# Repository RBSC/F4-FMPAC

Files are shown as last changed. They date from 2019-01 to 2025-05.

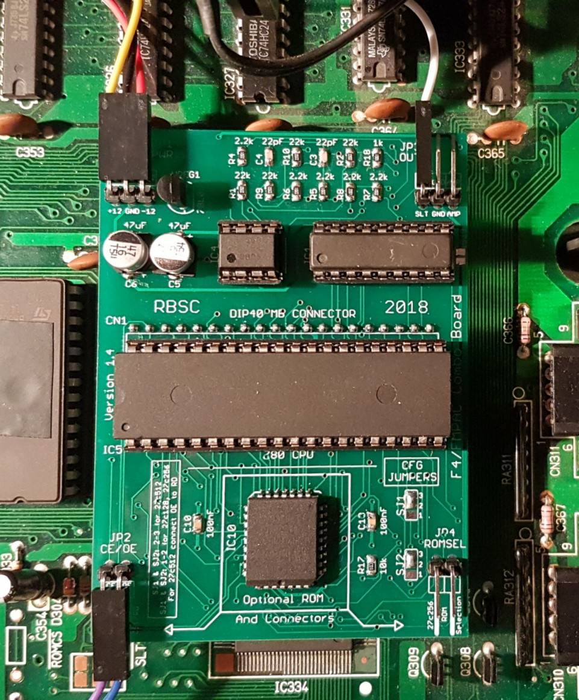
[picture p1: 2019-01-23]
Pics/assembled.jpg

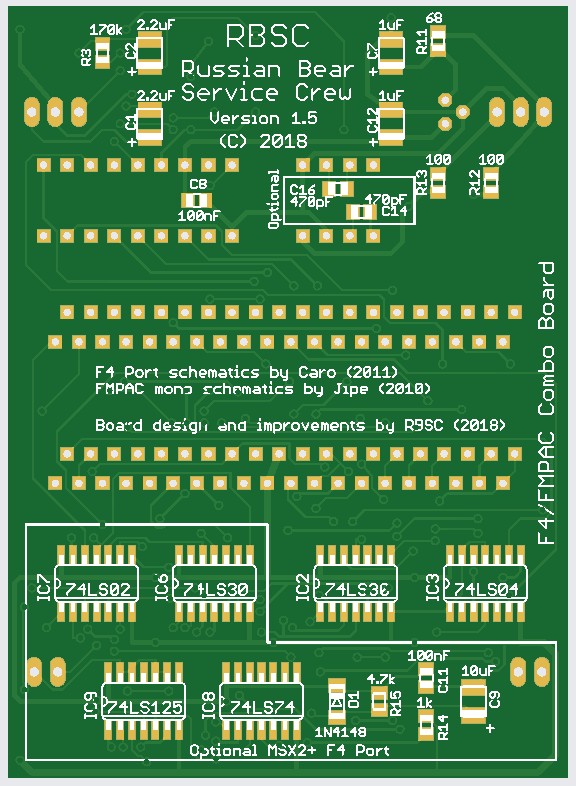
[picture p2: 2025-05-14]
Pics/board_back.jpg

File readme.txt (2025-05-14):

F4/FMPAC Combo Board version 1.5
Copyright (c) 2016-2025 RBSC
Portions (c) Kamil Karimov

Connection to the mainboard
---------------------------

The board requires a few wires to be connected to the MSX mainboard. The +12v and -12v are required for the FM chip and the
amplifier and must be connected to the JP1 connector. Also the GND (ground) must be connected to JP1, especially if the SJ3
solder jumper stays open. Those voltages and ground can be taken from the side slot of Yamaha MSX2 computers (YIS503, CX5M2
or CX7). On other computers those voltages could be taken from one of the slots or from the power supply's connection to the
mainboard.

The CE pin of the JP2 connector must be connected to the available STLSEL signal. On Yamaha MSX2 computers this could be taken
from the front slot (3.1). On other computers any unused slot signal could be used. The OE pin must be connected to CS1 signal
of the selected slot. However, in case of 27C512 EPROM installation, this pin must be connected to RD signal.

Audio connections
-----------------

The board has 2 different mono audio outputs marked as AMP and SLT. The AMP pin of JP3 must be only connected to the mixer point
of the internal amplifier, where all other SNDIN pins of cartridge slots are connected to. The AMP circuit already contains the
necessary resistor and capacitor and can be directly connected to the amplifier's input. To avoid interference from the other
components it's recommended to use the shielded wire. The shield should be connected to the GND pin of JP3.

The SLT pin of JP3 must be only connected to pin 49 (SNDIN) of any cartridge slot. On Yamaha MSX2 YIS503 and similar computers
the best place to connect the SLT pin is pin 59 on the side slot. Please be careful when connecting the wires - if not sure -
measure the voltages before connecting the wires. In correct connection could result in a damage for the board!

BIOS versions
-------------

The EPROM of the board contains 2 different FMPAC BIOSes. One is for external FMPAC (cartridge), the other is for internal FMPAC
(built-in into MSX2+). The BIOS is selected by JP4 jumper. It is recommended to use the internal FMPAC BIOS with the board. For
this option the jumper should not be installed.

Please pay special attention on the configuration notes on the board for solder jumpers SJ1 and SJ2! Those jumpers must be
configured correctly depending on the used EPROM chip. Otherwise FMPAC's BIOS will not work and there will be no FM music and
sounds in Basic as well as in certain games that detect the BIOS.

Notes
-----

The solderable jumper SJ3 is used to separate digital and analogue grounds. The board works fine without this jumper as long as
you connect the GND wire to JP1. The SJ3 should be only soldered if you don't connect GND to the board. But if you hear any
digital interference in the audio channel after you bridged the SJ3 jumper, please remove the bridge and connect GND wire to JP1.

The F4 Register part of the board is optional. It is only needed when the board is being installed into a computer that is converted
to MSX2+. Normal MSX1 or MSX2 computers don't need F4 port.

This FMPAC board does not support writing anything to SRAM (there's no SRAM on board). Also this device only provides mono sounds
and music. Stereo is not available.

Please note that the provided FMPAC BIOS image doesn't contain the UI (user interface). The full version of the FMPAC BIOS is
available in the RBSC's Carnivore2 cartridge. The BIOS is even translated into English.

IMPORTANT!
----------

The RBSC provides all the files and information for free, without any liability (see the disclaimer.txt file). The provided information,
software or hardware must not be used for commercial purposes unless permitted by the RBSC. Producing a small amount of bare boards for
personal projects and selling the rest of the batch is allowed without the permission of RBSC.

When the sources of the tools are used to create alternative projects, please always mention the original source and the copyright!

Contact information
-------------------

The members of RBSC group Tnt23, Wierzbowsky, Pyhesty, Ptero, GreyWolf, SuperMax, VWarlock, Alspru and DJS3000 can be contacted via the
group's e-mail address:

info@rbsc.su

The group's coordinator could be reached via this e-mail address:

admin@rbsc.su

The group's website can be found here:

https://rbsc.su/
https://rbsc.su/ru

The RBSC's hardware repository can be found here:

https://github.com/rbsc

The RBSC's 3D model repository can be found here:

https://www.thingiverse.com/groups/rbsc/things

-= ! MSX FOREVER ! =-

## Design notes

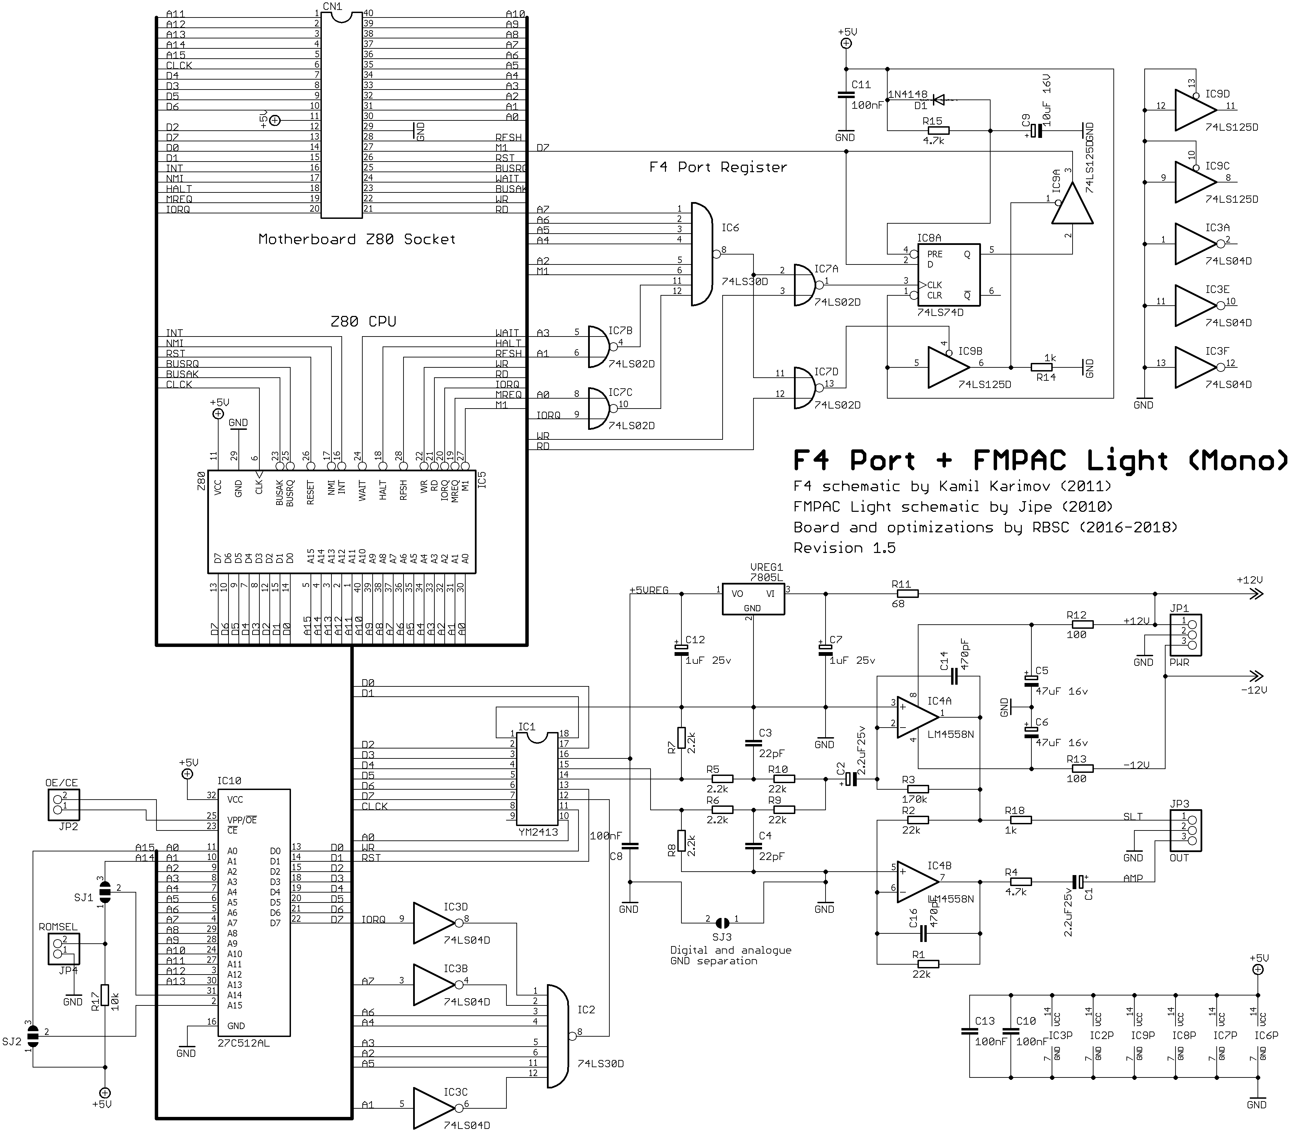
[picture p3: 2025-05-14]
Doc/schematics.png

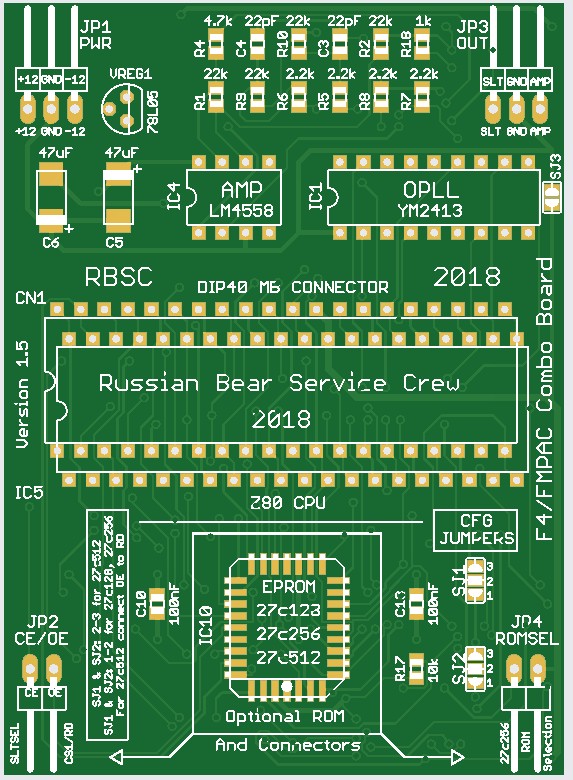
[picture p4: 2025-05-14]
Pics/board_front.jpg

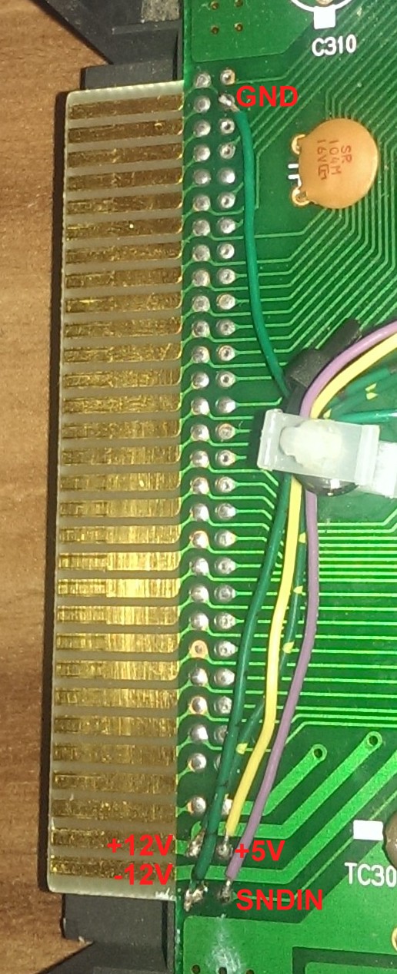
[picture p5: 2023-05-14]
Pics/sideslot.jpg

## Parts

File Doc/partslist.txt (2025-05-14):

Partlist

Part     Value          Device         Package  Library    Sheet

C1       2.2uF25v       CPOL-EUSMCB    SMC_B    rcl        1
C2       2.2uF25v       CPOL-EUSMCB    SMC_B    rcl        1
C3       22pF           C-EUC0805      C0805    rcl        1
C4       22pF           C-EUC0805      C0805    rcl        1
C5       47uF 16v       CPOL-EUSMCC    SMC_C    rcl        1
C6       47uF 16v       CPOL-EUSMCC    SMC_C    rcl        1
C7       1uF 25v        CPOL-EUSMCB    SMC_B    rcl        1
C8       100nF          C-EUC0805      C0805    rcl        1
C9       10uF 16V       CPOL-EUSMCB    SMC_B    rcl        1
C10      100nF          C-EUC0805      C0805    rcl        1
C11      100nF          C-EUC0805      C0805    rcl        1
C12      1uF 25v        CPOL-EUSMCB    SMC_B    rcl        1
C13      100nF          C-EUC0805      C0805    rcl        1
C14      470pF          C-EUC0805      C0805    rcl        1
C16      470pF          C-EUC0805      C0805    rcl        1
CN1      DIP40 MB CONN  DIL40          DIL40    ic-package 1
D1       1N4148         DIODE-MINIMELF MINIMELF diode      1
IC1      YM2413         DIL18          DIL18    ic-package 1
IC2      74LS30D        74LS30D        SO14     74xx-eu    1
IC3      74LS04D        74LS04D        SO14     74xx-eu    1
IC4      LM4558N        LM4558N        DIL08    linear     1
IC5      Z80            Z80CPU         DIL40    zilog      1
IC6      74LS30D        74LS30D        SO14     74xx-eu    1
IC7      74LS02D        74LS02D        SO14     74xx-eu    1
IC8      74LS74D        74LS74D        SO14     74xx-eu    1
IC9      74LS125D       74LS125D       SO14     74xx-eu    1
IC10     27C512AL       27C512AL       PLCC-32  microchip  1
JP1      PWR            PINHD-1X3/90   1X03/90  pinhead    1
JP2      OE/CE          PINHD-1X2/90   1X02/90  pinhead    1
JP3      OUT            PINHD-1X3/90   1X03/90  pinhead    1
JP4      ROMSEL         PINHD-1X2/90   1X02/90  pinhead    1
R1       22k            R-EU_R0805     R0805    rcl        1
R2       22k            R-EU_R0805     R0805    rcl        1
R3       170k           R-EU_R0805     R0805    rcl        1
R4       4.7k           R-EU_R0805     R0805    rcl        1
R5       2.2k           R-EU_R0805     R0805    rcl        1
R6       2.2k           R-EU_R0805     R0805    rcl        1
R7       2.2k           R-EU_R0805     R0805    rcl        1
R8       2.2k           R-EU_R0805     R0805    rcl        1
R9       22k            R-EU_R0805     R0805    rcl        1
R10      22k            R-EU_R0805     R0805    rcl        1
R11      68             R-EU_R0805     R0805    rcl        1
R12      100            R-EU_R0805     R0805    rcl        1
R13      100            R-EU_R0805     R0805    rcl        1
R14      1k             R-EU_R0805     R0805    rcl        1
R15      4.7k           R-EU_M0805     M0805    rcl        1
R17      10k            R-EU_R0805     R0805    rcl        1
R18      1k             R-EU_R0805     R0805    rcl        1
SJ1                     SJ2W           SJ_2     jumper     1
SJ2                     SJ2W           SJ_2     jumper     1
SJ3                     SJ             SJ       jumper     1
VREG1    7805L          7805L          TO92     linear     1

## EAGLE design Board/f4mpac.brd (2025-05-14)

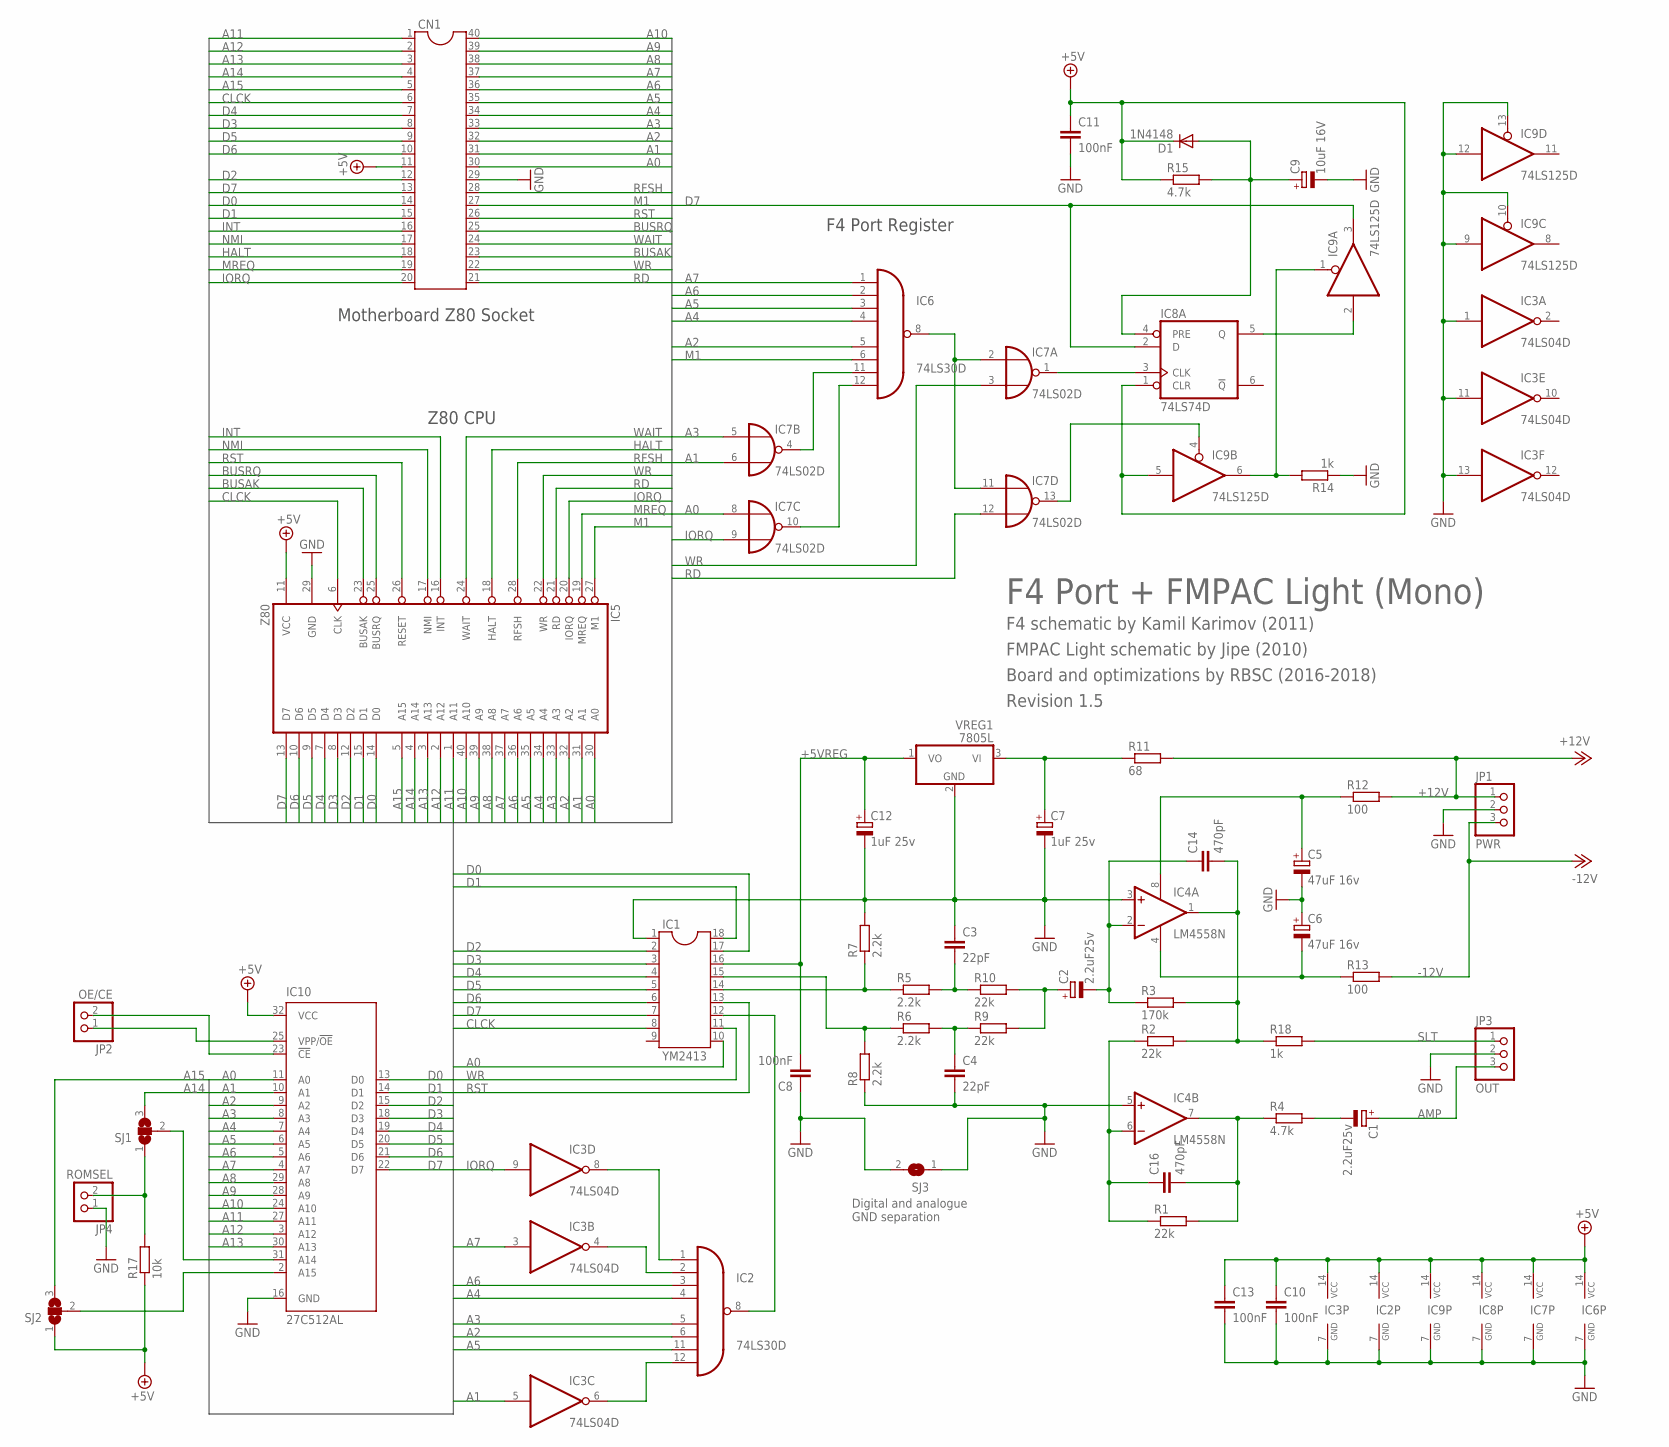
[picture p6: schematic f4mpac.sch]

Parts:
C1, C2: 2.2uF25v; SMC_B
C3, C4: 22pF; C0805
C5, C6: 47uF 16v; SMC_C
C7, C12: 1uF 25v; SMC_B
C8, C10, C11, C13: 100nF; C0805
C9: 10uF 16V; SMC_B
C14, C16: 470pF; C0805
CN1: DIP40 MB CONN; DIL40
D1: 1N4148; MINIMELF
IC1: YM2413; DIL18
IC2, IC6: 74LS30D; SO14
IC3: 74LS04D; SO14
IC4: LM4558N; DIL08
IC5: Z80; DIL40
IC7: 74LS02D; SO14
IC8: 74LS74D; SO14
IC9: 74LS125D; SO14
IC10: 27C512AL; PLCC-32
JP1: PWR; 1X03/90
JP2: OE/CE; 1X02/90
JP3: OUT; 1X03/90
JP4: ROMSEL; 1X02/90
R1, R2, R9, R10: 22k; R0805
R3: 170k; R0805
R4: 4.7k; R0805
R5, R6, R7, R8: 2.2k; R0805
R11: 68; R0805
R12, R13: 100; R0805
R14, R18: 1k; R0805
R15: 4.7k; M0805
R17: 10k; R0805
SJ1, SJ2: SJ2W; SJ_2
SJ3: SJ
VREG1: 7805L; TO92

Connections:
+5V: C10.1, C11.1, C13.1, CN1.11, D1.C, IC2.14 (VCC), IC3.14 (VCC), IC5.11 (VCC), IC6.14 (VCC), IC7.14 (VCC), IC8.1 (CLR), IC8.14 (VCC), IC9.5 (I), IC9.14 (VCC), IC10.32 (VCC), R15.1, R17.1, SJ2.1
+5VREG: C8.2, C12.+, IC1.16, VREG1.1 (VO)
+12V: JP1.1, R11.2, R12.2
+12VAMP: C5.+, IC4.8 (V+), R12.1
-12V: JP1.3, R13.2
-12VAMP: C6.-, IC4.4 (V-), R13.1
A0: CN1.30, IC1.10, IC5.30 (A0), IC7.8 (I0), IC10.11 (A0)
A1: CN1.31, IC3.5 (I), IC5.31 (A1), IC7.6 (I1), IC10.10 (A1)
A2: CN1.32, IC2.6 (I5), IC5.32 (A2), IC6.5 (I4), IC10.9 (A2)
A3: CN1.33, IC2.5 (I4), IC5.33 (A3), IC7.5 (I0), IC10.8 (A3)
A4: CN1.34, IC2.4 (I3), IC5.34 (A4), IC6.4 (I3), IC10.7 (A4)
A5: CN1.35, IC2.11 (I6), IC5.35 (A5), IC6.3 (I2), IC10.6 (A5)
A6: CN1.36, IC2.3 (I2), IC5.36 (A6), IC6.2 (I1), IC10.5 (A6)
A7: CN1.37, IC3.3 (I), IC5.37 (A7), IC6.1 (I0), IC10.4 (A7)
A8: CN1.38, IC5.38 (A8), IC10.29 (A8)
A9: CN1.39, IC5.39 (A9), IC10.28 (A9)
A10: CN1.40, IC5.40 (A10), IC10.24 (A10)
A11: CN1.1, IC5.1 (A11), IC10.27 (A11)
A12: CN1.2, IC5.2 (A12), IC10.3 (A12)
A13: CN1.3, IC5.3 (A13), IC10.30 (A13)
A14: CN1.4, IC5.4 (A14), SJ1.3
A15: CN1.5, IC5.5 (A15), SJ2.3
AMP: C1.+, JP3.3
BUSAK: CN1.23, IC5.23 (BUSAK)
BUSRQ: CN1.25, IC5.25 (BUSRQ)
CLCK: CN1.6, IC1.8, IC5.6 (CLK)
D0: CN1.14, IC1.17, IC5.14 (D0), IC10.13 (D0)
D1: CN1.15, IC1.18, IC5.15 (D1), IC10.14 (D1)
D2: CN1.12, IC1.2, IC5.12 (D2), IC10.15 (D2)
D3: CN1.8, IC1.3, IC5.8 (D3), IC10.18 (D3)
D4: CN1.7, IC1.4, IC5.7 (D4), IC10.19 (D4)
D5: CN1.9, IC1.5, IC5.9 (D5), IC10.20 (D5)
D6: CN1.10, IC1.6, IC5.10 (D6), IC10.21 (D6)
D7: CN1.13, IC1.7, IC5.13 (D7), IC8.2 (D), IC9.3 (O), IC10.22 (D7)
GND: C3.1, C4.2, C5.-, C6.+, C7.-, C8.1, C9.-, C10.2, C11.2, C12.-, C13.2, CN1.29, IC1.1, IC2.7 (GND), IC3.1 (I), IC3.7 (GND), IC3.11 (I), IC3.13 (I), IC4.3 (+IN), IC4.5 (+IN), IC5.29 (GND), IC6.7 (GND), IC7.7 (GND), IC8.7 (GND), IC9.7 (GND), IC9.9 (I), IC9.10 (OE), IC9.12 (I), IC9.13 (OE), IC10.16 (GND), JP1.2, JP3.2, JP4.1, R7.2, R8.1, R14.1, SJ3.1, SJ3.2, VREG1.2 (GND)
HALT: CN1.18, IC5.18 (HALT)
INT: CN1.16, IC5.16 (INT)
IORQ: CN1.20, IC3.9 (I), IC5.20 (IORQ), IC7.9 (I1)
M1: CN1.27, IC5.27 (M1), IC6.6 (I5)
MREQ: CN1.19, IC5.19 (MREQ)
unnamed: IC1.12, IC2.8 (O)
unnamed: IC10.31 (A14), SJ1.2
unnamed: C7.+, R11.1, VREG1.3 (VI)
unnamed: IC1.14, R5.1, R7.1
unnamed: C2.-, C14.1, IC4.2 (-IN), R3.1
unnamed: C16.1, IC4.6 (-IN), R1.1, R2.1
unnamed: C1.-, R4.2
unnamed: C3.2, R5.2, R10.1
unnamed: IC1.15, R6.1, R8.2
unnamed: C4.1, R6.2, R9.1
unnamed: IC2.12 (I7), IC3.6 (O)
unnamed: C2.+, R9.2, R10.2
unnamed: IC2.2 (I1), IC3.4 (O)
unnamed: IC2.1 (I0), IC3.8 (O)
unnamed: C9.+, D1.A, IC8.4 (PRE), R15.2
unnamed: IC10.25 (VPP/!OE), JP2.1
unnamed: IC10.23 (!CE), JP2.2
unnamed: JP4.2, R17.2, SJ1.1
unnamed: IC6.11 (I6), IC7.4 (O)
unnamed: IC10.2 (A15), SJ2.2
unnamed: C16.2, IC4.7 (OUT), R1.2, R4.1
unnamed: IC6.12 (I7), IC7.10 (O)
unnamed: IC7.1 (O), IC8.3 (CLK)
unnamed: IC7.13 (O), IC9.4 (OE)
unnamed: IC6.8 (O), IC7.2 (I0), IC7.11 (I0)
unnamed: IC9.1 (OE), IC9.6 (O), R14.2
unnamed: C14.2, IC4.1 (OUT), R2.2, R3.2, R18.1
unnamed: IC8.5 (Q), IC9.2 (I)
NMI: CN1.17, IC5.17 (NMI)
RD: CN1.21, IC5.21 (RD), IC7.12 (I1)
RFSH: CN1.28, IC5.28 (RFSH)
RST: CN1.26, IC1.13, IC5.26 (RESET)
SLT: JP3.1, R18.2
WAIT: CN1.24, IC5.24 (WAIT)
WR: CN1.22, IC1.11, IC5.22 (WR), IC7.3 (I1)

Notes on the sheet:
F4 Port Register
Z80 CPU
Motherboard Z80 Socket
F4 schematic by Kamil Karimov (2011)
FMPAC Light schematic by Jipe (2010)
F4 Port + FMPAC Light (Mono)
Board and optimizations by RBSC (2016-2018)
Digital and analogue GND separation
Revision 1.5

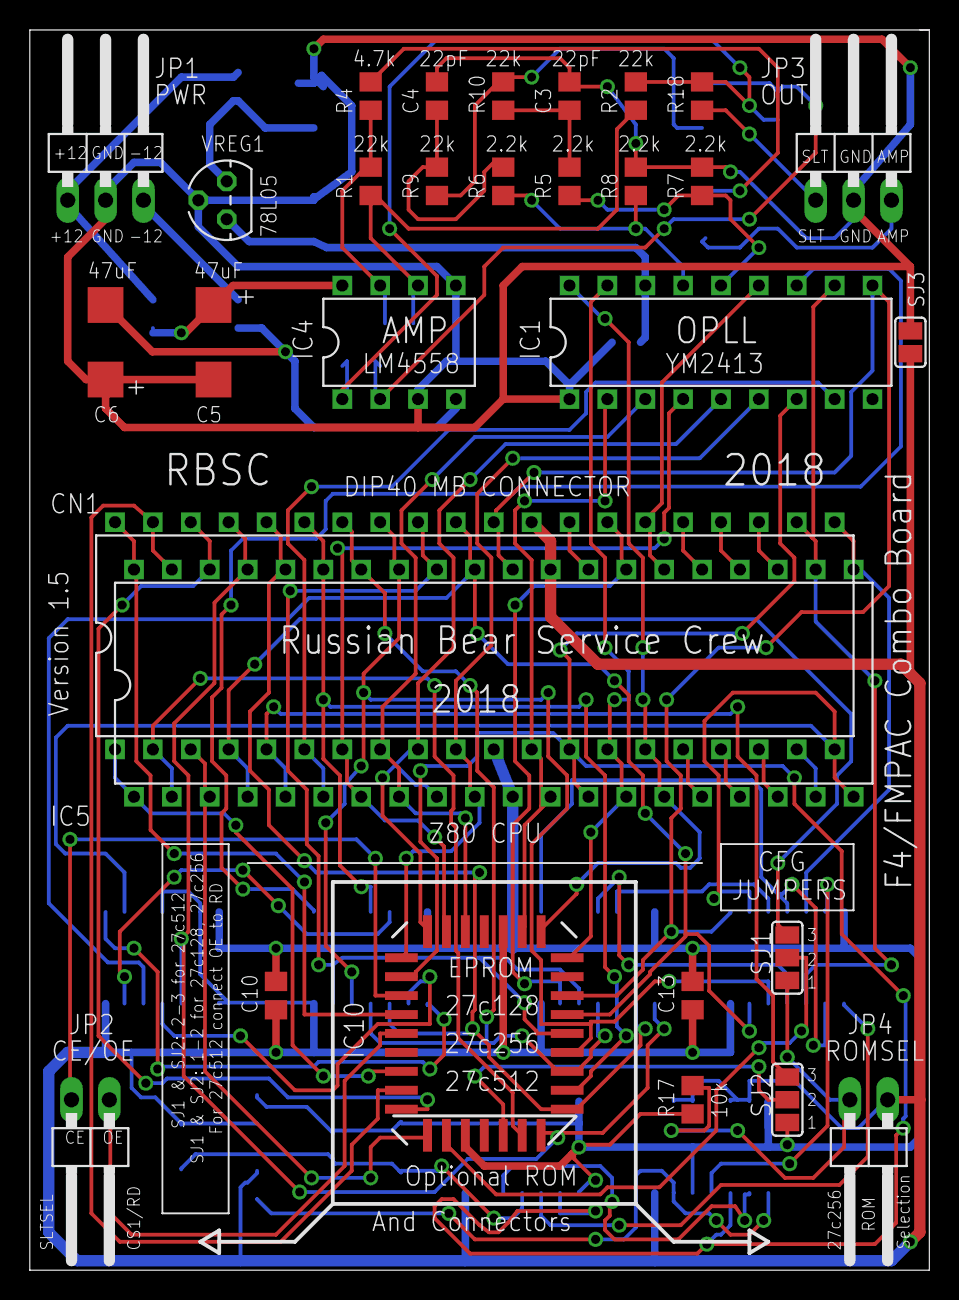
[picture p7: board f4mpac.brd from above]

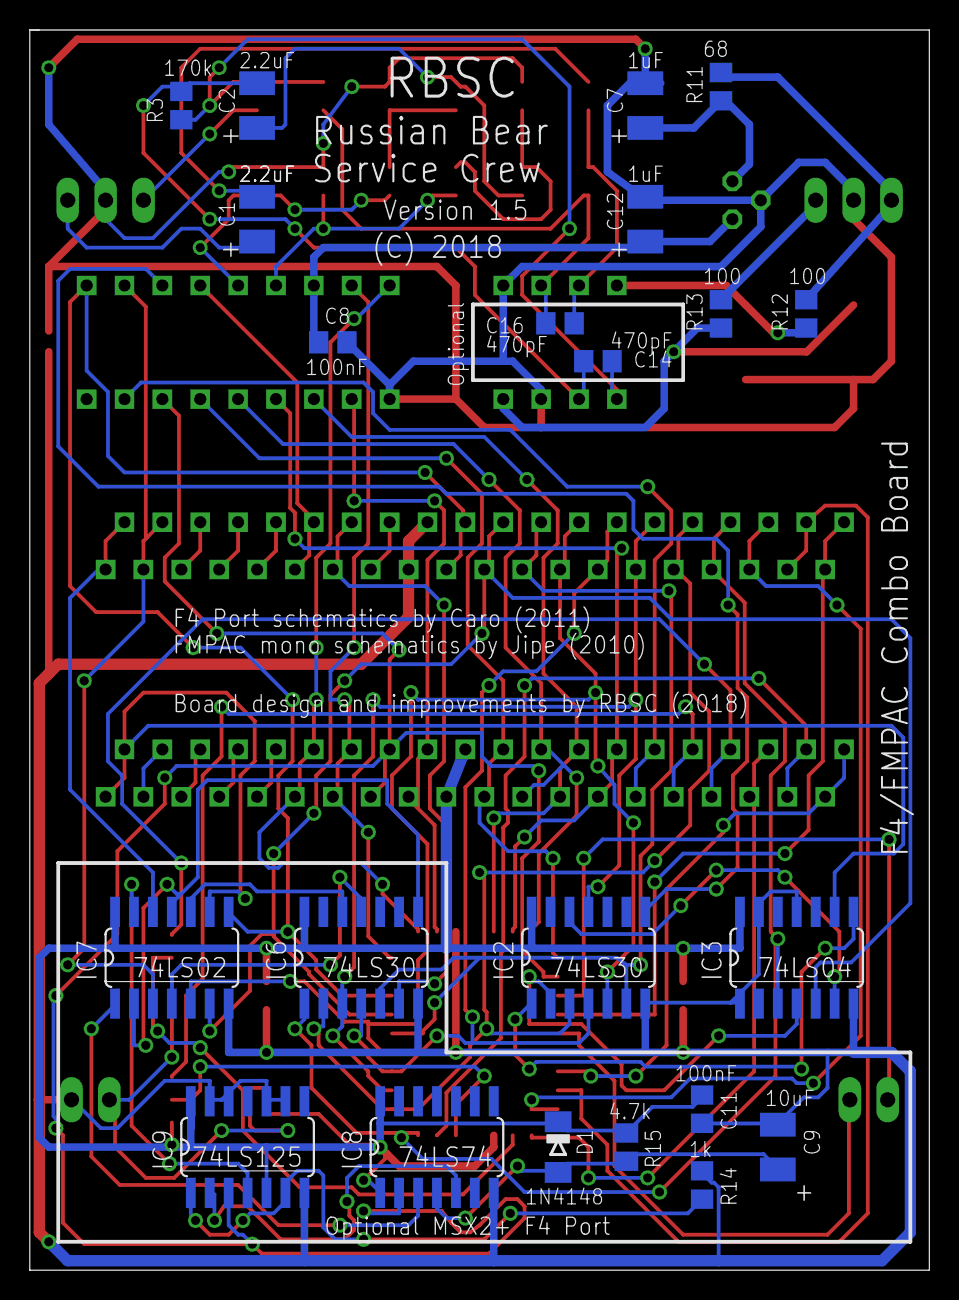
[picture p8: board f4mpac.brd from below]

Board: 2 copper layers, 60.3 x 83.2 mm, 52 parts (22 on the bottom side), 75 nets.

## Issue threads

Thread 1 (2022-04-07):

fix the circuit!

darleiv, 2022-04-07:
438 / 5.000
Resultados de tradução
Please . fix the C6. that the poles are inverted and can cause an explosion in the user's hand. . and add 100nf coupling capacitors to each logic gate in the circuit this is a simple electronic rule. and put 47UF capacitors on the B+ 5V decoupling. when you put a project on google you should warn that it may contain errors in the circuit and it is in BETA version. This is missing from your GIT. See you soon
https://ibb.co/hYc2Wrp

Wierzbowsky, 2022-04-07:
The circuit is correct. The capacitor is connected to -12v rail, so its minus goes to the -12v and plus goes to the ground.

Closed 2022-04-07.

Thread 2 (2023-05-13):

pcb error

nuni38317, 2023-05-13:
In pcb,  C8 cap gnd is not connected to GND

Wierzbowsky, 2023-05-14:
Confirmed, many thanks! Not critical, but will be fixed and deployed to repository ASAP.

Closed 2023-05-14.

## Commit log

2016-01-26 Version 2 of the board
    [f4mpac.brd, f4mpac.sch]
2016-03-05 New board version 1.3
    New board version 1.3, new combined and selectable ROM, easier to get
    ROM chip, corrected names error, blocking capacitors, additional noise
    suppressing capacitor
    [f4mpac.brd, f4mpac.sch]
2017-04-26 Updated source and gerber files, added schematics
    [f4mpac.brd, f4mpac.sch]
2017-05-20 Added readme files
    [f4mpac.brd, f4mpac.sch]
2019-01-23 Release 23.01.2019
    Improved board, redrawn schematics
    [f4mpac.brd, f4mpac.sch]
2023-05-14 Updated 14.05.2023
    Small correction on the board for non-critical problem
    [f4mpac.GBL, f4mpac.GBO, f4mpac.GBP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]
2025-05-14 Updated 14.05.2025
    Updated the board to version 1.5. Corrected R4, C14 and C16 values. Updated readme file.
    [f4mpac.brd, f4mpac.sch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]

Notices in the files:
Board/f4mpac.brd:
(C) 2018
